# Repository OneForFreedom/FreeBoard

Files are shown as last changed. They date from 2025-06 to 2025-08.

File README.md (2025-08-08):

# FreeBoard
Freedom's Keyboard
This is my first keyboard! I had a blast desgining it and I'd thought I'd a nice black and red layout. This contains 3 rotary encoders cuz why not?

# Some cool mouthwatering visuals:

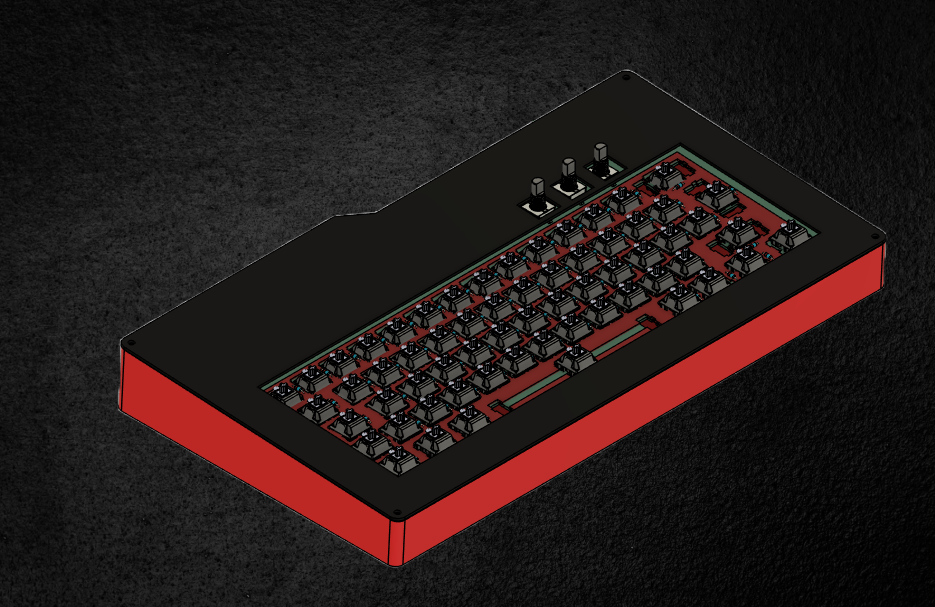
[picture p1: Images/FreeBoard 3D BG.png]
FreeBoard 3D BG
  
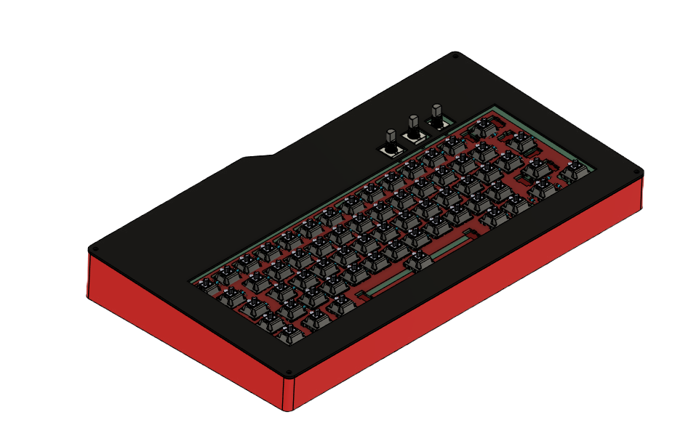
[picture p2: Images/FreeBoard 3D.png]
FreeBoard 3D
  
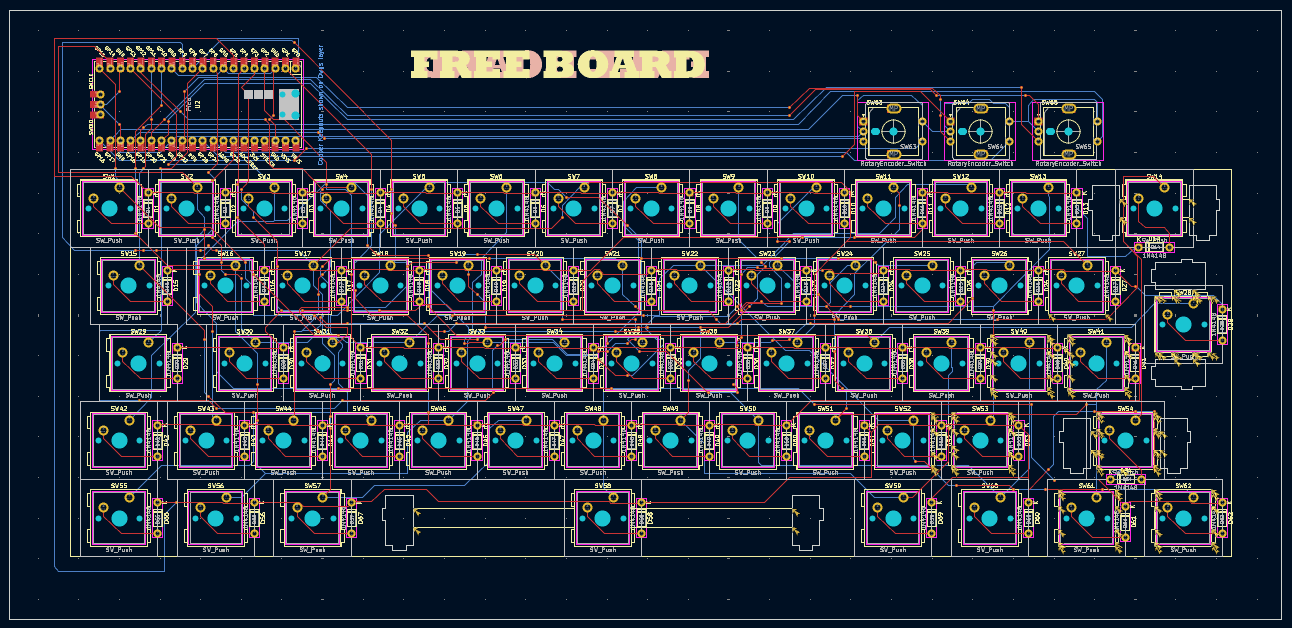
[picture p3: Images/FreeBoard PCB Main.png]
FreeBoard PCB Main
  
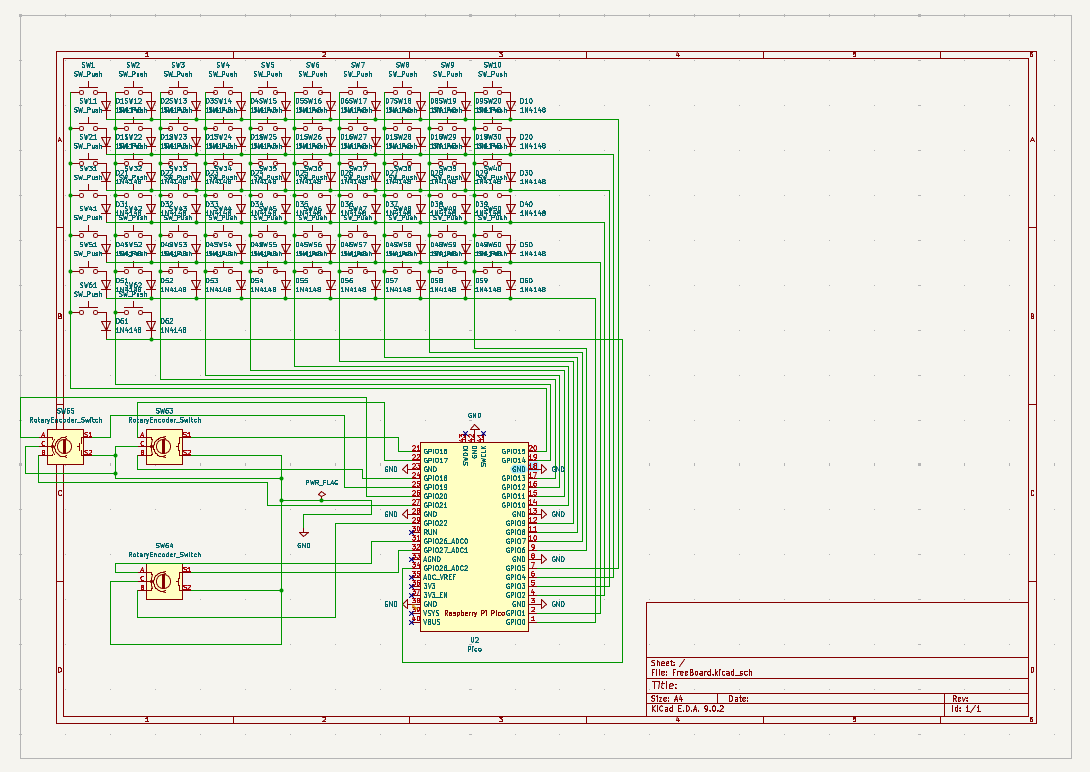
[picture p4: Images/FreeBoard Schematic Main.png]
FreeBoard Schematic Main
  
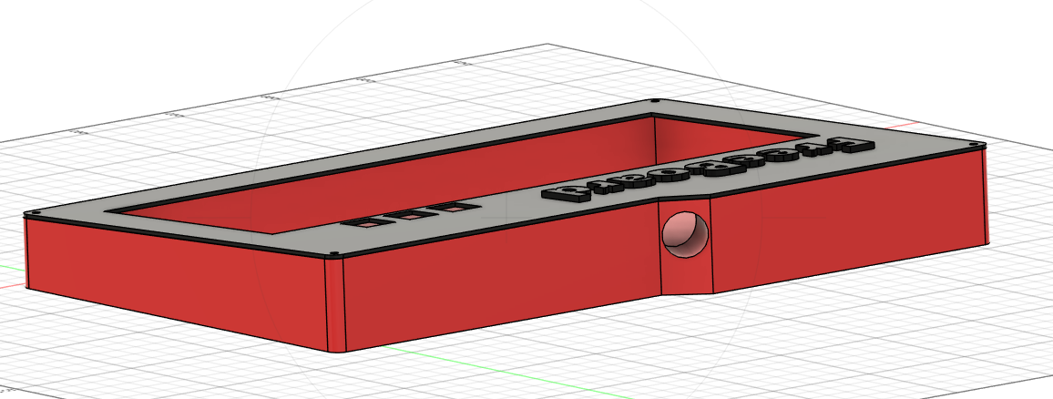
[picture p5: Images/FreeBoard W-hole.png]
FreeBoard Backside
  
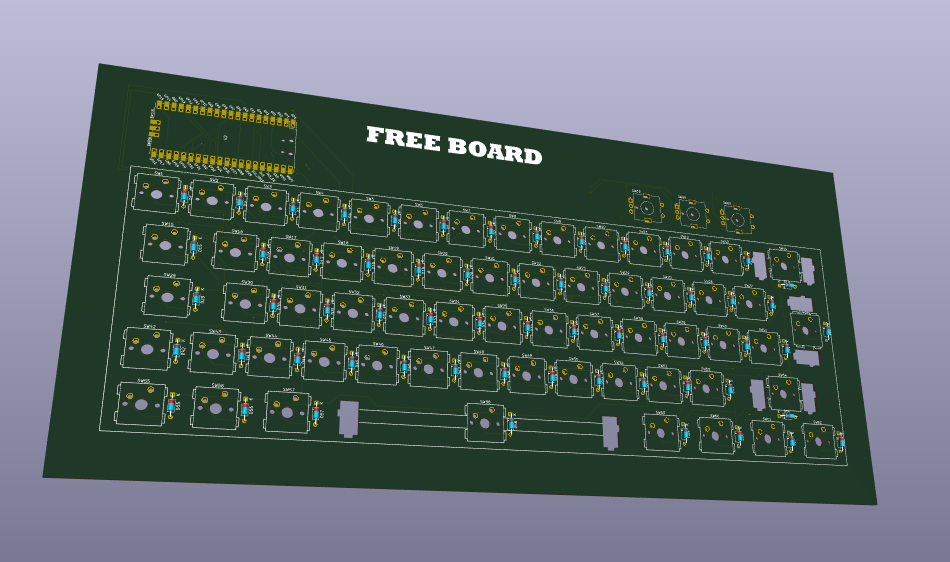
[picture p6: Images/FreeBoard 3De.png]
FreeBoard PCB 3D


# Bill Of Materials (BOM)

NEEDS COMPLETE REDO!

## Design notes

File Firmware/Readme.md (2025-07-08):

Basically this keyboard is a 60% uk iso keyboard (yes the one with the big upside down L)

The main keys are self explanatory.
The first rotary encoder (going from left) Does volumne control, twist it to adjust vol, and press it to mute/unmute it.
Second is for seeking tracks and pausing and playing, and 
third is null (idk what to do yet)

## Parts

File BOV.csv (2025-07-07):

Item | Quantity | Price (GBP) | Total (GBP) | Price (USD) | Total (USD) | Link
Pico Micro | 1 | 1.90 | 1.90 | 2.58 | 2.58 | https://www.aliexpress.com/item/1005008513003531.html?mp=1
Keycaps | 1 | 7.69 | 7.69 | 10.46 | 10.46 | https://www.aliexpress.com/item/1005004536761030.html?mp=1
O-Rings | 1 | 0.57 | 0.57 | 0.78 | 0.78 | https://www.aliexpress.com/item/32965363255.html?mp=1
Keyswitches | 1 | 21.39 | 21.39 | 29.09 | 29.09 | https://www.aliexpress.com/item/1005006425450443.html?mp=1
Cable | 1 | 0.92 | 0.92 | 1.25 | 1.25 | https://www.aliexpress.com/item/1005007138392516.html?mp=1
EC11 Cap | 1 | 1.06 | 1.06 | 1.44 | 1.44 | https://www.aliexpress.com/item/1005005983134515.html?mp=1
EC11 | 1 | 1.89 | 1.89 | 2.57 | 2.57 | https://www.aliexpress.com/item/1005005983134515.html?mp=1
Diodes (x3) | 3 | 0.70 | 2.10 | 0.95 | 2.86 | https://www.aliexpress.com/item/1005006245109375.html?mp=1
Switchpads | 1 | 2.52 | 2.52 | 3.43 | 3.43 | https://www.aliexpress.com/item/1005006454684461.html?mp=1
Switch Film | 1 | 2.00 | 2.00 | 2.72 | 2.72 | https://www.aliexpress.com/item/1005006584258877.html?mp=1
PCB | 1 | 28.65 | 28.65 | 38.95 | 38.95 | https://cart.jlcpcb.com/
Royal Mail Shipping | 1 | 5.00 | 5.00 | 6.80 | 6.80 | https://send.royalmail.com/send/youritem?country=GBR&format&weight=&weightUnit=G

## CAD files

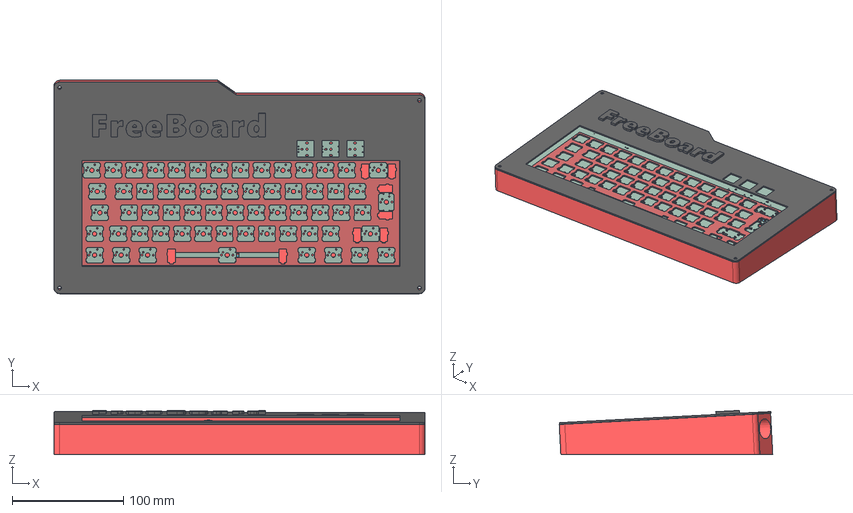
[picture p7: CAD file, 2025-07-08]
FreeBoard Assembled.step
333.0 x 191.7 x 39.6 mm
D_DO-35_SOD27_P7.62mm_Horizontal x 62
FreeBoard_PCB

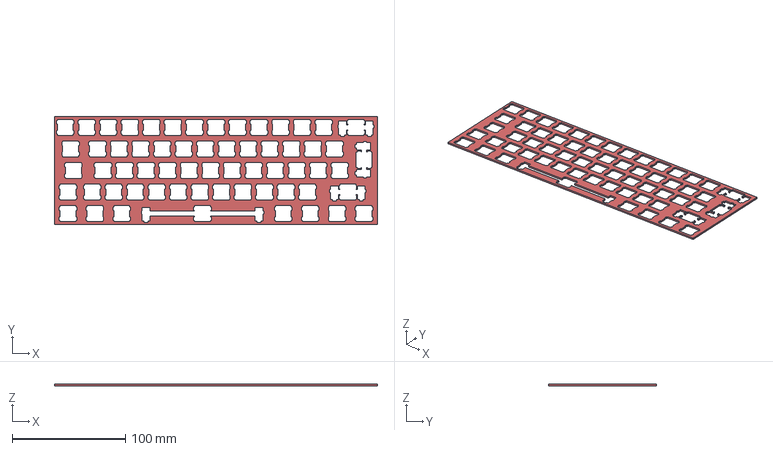
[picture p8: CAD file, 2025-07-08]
Cad/FreeBoard Plate.step
285.7 x 95.2 x 1.50 mm

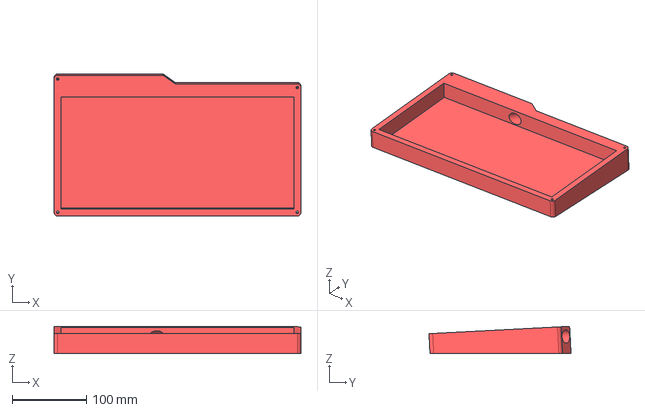
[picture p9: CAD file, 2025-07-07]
Production/FreeBoard Bottom.step
333.0 x 191.7 x 36.9 mm

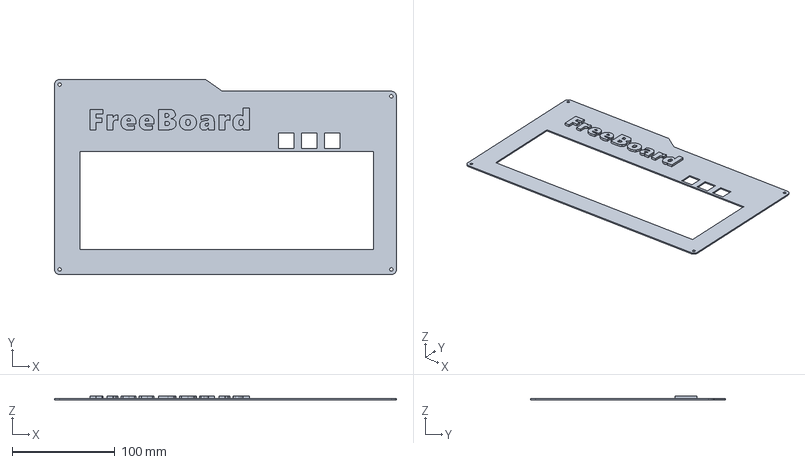
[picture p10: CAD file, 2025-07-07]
Production/FreeBoard Top.step
333.0 x 190.0 x 4.00 mm

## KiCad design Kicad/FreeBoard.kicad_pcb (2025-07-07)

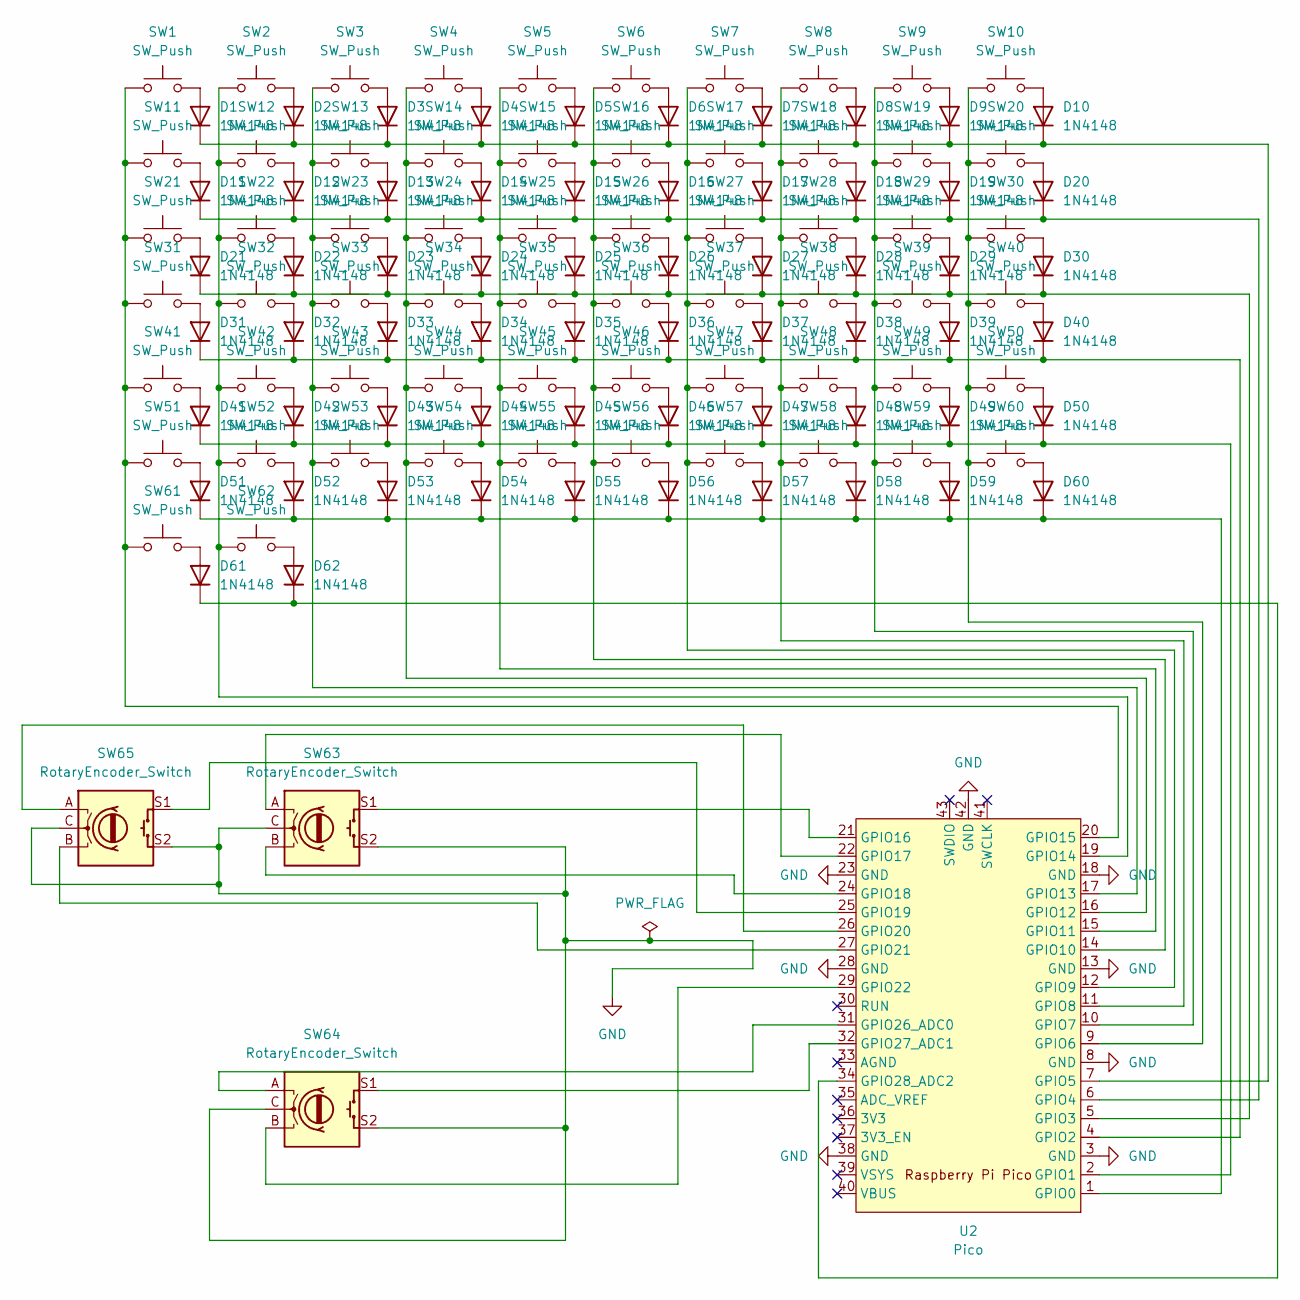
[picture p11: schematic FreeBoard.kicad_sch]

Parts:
D1, D2, D3, D4, D5, D6, D7, D8, D9, D10, D11, D12, D13, D14, D15, D16, D17, D18, D19, D20, D21, D22, D23, D24, D25, D26, D27, D28, D29, D30, D31, D32, D33, D34, D35, D36, D37, D38, D39, D40, D41, D42, D43, D44, D45, D46, D47, D48, D49, D50, D51, D52, D53, D54, D55, D56, D57, D58, D59, D60, D61, D62: 1N4148; D_DO-35_SOD27_P7.62mm_Horizontal
SW1, SW2, SW3, SW4, SW5, SW6, SW7, SW8, SW9, SW10, SW11, SW12, SW13, SW14, SW15, SW16, SW17, SW18, SW19, SW20, SW21, SW22, SW23, SW24, SW25, SW26, SW27, SW28, SW29, SW30, SW31, SW32, SW33, SW34, SW35, SW36, SW37, SW38, SW39, SW40, SW41, SW42, SW43, SW44, SW45, SW46, SW47, SW48, SW49, SW50, SW51, SW52, SW53, SW54, SW55, SW56, SW57, SW58, SW59, SW60, SW61, SW62: SW_Push; SW_Cherry_MX_1.00u_PCB
SW63, SW64, SW65: RotaryEncoder_Switch; RotaryEncoder_Alps_EC11E-Switch_Vertical_H20mm_MountingHoles
U2: Pico; RPi_Pico_SMD_TH

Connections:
GND: SW63.C, SW63.S2, SW64.C, SW64.S2, SW65.C, SW65.S2, U2.3 (GND), U2.8 (GND), U2.13 (GND), U2.18 (GND), U2.23 (GND), U2.28 (GND), U2.38 (GND), U2.42 (GND)
unnamed: D1.2 (A), SW1.2
unnamed: D1.1 (K), D2.1 (K), D3.1 (K), D4.1 (K), D5.1 (K), D6.1 (K), D7.1 (K), D8.1 (K), D9.1 (K), D10.1 (K), U2.7 (GPIO5)
unnamed: D2.2 (A), SW2.2
unnamed: D3.2 (A), SW3.2
unnamed: D4.2 (A), SW4.2
unnamed: D5.2 (A), SW5.2
unnamed: D6.2 (A), SW6.2
unnamed: D7.2 (A), SW7.2
unnamed: D8.2 (A), SW8.2
unnamed: D9.2 (A), SW9.2
unnamed: D10.2 (A), SW10.2
unnamed: D11.2 (A), SW11.2
unnamed: D11.1 (K), D12.1 (K), D13.1 (K), D14.1 (K), D15.1 (K), D16.1 (K), D17.1 (K), D18.1 (K), D19.1 (K), D20.1 (K), U2.6 (GPIO4)
unnamed: D12.2 (A), SW12.2
unnamed: D13.2 (A), SW13.2
unnamed: D14.2 (A), SW14.2
unnamed: D15.2 (A), SW15.2
unnamed: D16.2 (A), SW16.2
unnamed: D17.2 (A), SW17.2
unnamed: D18.2 (A), SW18.2
unnamed: D19.2 (A), SW19.2
unnamed: D20.2 (A), SW20.2
unnamed: D21.2 (A), SW21.2
unnamed: D21.1 (K), D22.1 (K), D23.1 (K), D24.1 (K), D25.1 (K), D26.1 (K), D27.1 (K), D28.1 (K), D29.1 (K), D30.1 (K), U2.5 (GPIO3)
unnamed: D22.2 (A), SW22.2
unnamed: D23.2 (A), SW23.2
unnamed: D24.2 (A), SW24.2
unnamed: D25.2 (A), SW25.2
unnamed: D26.2 (A), SW26.2
unnamed: D27.2 (A), SW27.2
unnamed: D28.2 (A), SW28.2
unnamed: D29.2 (A), SW29.2
unnamed: D30.2 (A), SW30.2
unnamed: D31.2 (A), SW31.2
unnamed: D31.1 (K), D32.1 (K), D33.1 (K), D34.1 (K), D35.1 (K), D36.1 (K), D37.1 (K), D38.1 (K), D39.1 (K), D40.1 (K), U2.4 (GPIO2)
unnamed: D32.2 (A), SW32.2
unnamed: D33.2 (A), SW33.2
unnamed: D34.2 (A), SW34.2
unnamed: D35.2 (A), SW35.2
unnamed: D36.2 (A), SW36.2
unnamed: D37.2 (A), SW37.2
unnamed: D38.2 (A), SW38.2
unnamed: D39.2 (A), SW39.2
unnamed: D40.2 (A), SW40.2
unnamed: D41.2 (A), SW41.2
unnamed: D41.1 (K), D42.1 (K), D43.1 (K), D44.1 (K), D45.1 (K), D46.1 (K), D47.1 (K), D48.1 (K), D49.1 (K), D50.1 (K), U2.2 (GPIO1)
unnamed: D42.2 (A), SW42.2
unnamed: D43.2 (A), SW43.2
unnamed: D44.2 (A), SW44.2
unnamed: D45.2 (A), SW45.2
unnamed: D46.2 (A), SW46.2
unnamed: D47.2 (A), SW47.2
unnamed: D48.2 (A), SW48.2
unnamed: D49.2 (A), SW49.2
unnamed: D50.2 (A), SW50.2
unnamed: D51.2 (A), SW51.2
unnamed: D51.1 (K), D52.1 (K), D53.1 (K), D54.1 (K), D55.1 (K), D56.1 (K), D57.1 (K), D58.1 (K), D59.1 (K), D60.1 (K), U2.1 (GPIO0)
unnamed: D52.2 (A), SW52.2
unnamed: D53.2 (A), SW53.2
unnamed: D54.2 (A), SW54.2
unnamed: D55.2 (A), SW55.2
unnamed: D56.2 (A), SW56.2
unnamed: D57.2 (A), SW57.2
unnamed: D58.2 (A), SW58.2
unnamed: D59.2 (A), SW59.2
unnamed: D60.2 (A), SW60.2
unnamed: D61.2 (A), SW61.2
unnamed: D61.1 (K), D62.1 (K), U2.34 (GPIO28_ADC2)
unnamed: D62.2 (A), SW62.2
unnamed: SW10.1, SW20.1, SW30.1, SW40.1, SW50.1, SW60.1, U2.9 (GPIO6)
unnamed: SW9.1, SW19.1, SW29.1, SW39.1, SW49.1, SW59.1, U2.10 (GPIO7)
unnamed: SW8.1, SW18.1, SW28.1, SW38.1, SW48.1, SW58.1, U2.11 (GPIO8)
unnamed: SW7.1, SW17.1, SW27.1, SW37.1, SW47.1, SW57.1, U2.12 (GPIO9)
unnamed: SW6.1, SW16.1, SW26.1, SW36.1, SW46.1, SW56.1, U2.14 (GPIO10)
unnamed: SW5.1, SW15.1, SW25.1, SW35.1, SW45.1, SW55.1, U2.15 (GPIO11)
unnamed: SW4.1, SW14.1, SW24.1, SW34.1, SW44.1, SW54.1, U2.16 (GPIO12)
unnamed: SW3.1, SW13.1, SW23.1, SW33.1, SW43.1, SW53.1, U2.17 (GPIO13)
unnamed: SW2.1, SW12.1, SW22.1, SW32.1, SW42.1, SW52.1, SW62.1, U2.19 (GPIO14)
unnamed: SW1.1, SW11.1, SW21.1, SW31.1, SW41.1, SW51.1, SW61.1, U2.20 (GPIO15)
unnamed: SW63.S1, U2.21 (GPIO16)
unnamed: SW63.A, U2.22 (GPIO17)
unnamed: SW63.B, U2.24 (GPIO18)
unnamed: SW65.S1, U2.25 (GPIO19)
unnamed: SW65.A, U2.26 (GPIO20)
unnamed: SW65.B, U2.27 (GPIO21)
unnamed: SW64.B, U2.29 (GPIO22)
unnamed: SW64.A, U2.31 (GPIO26_ADC0)
unnamed: SW64.S1, U2.32 (GPIO27_ADC1)

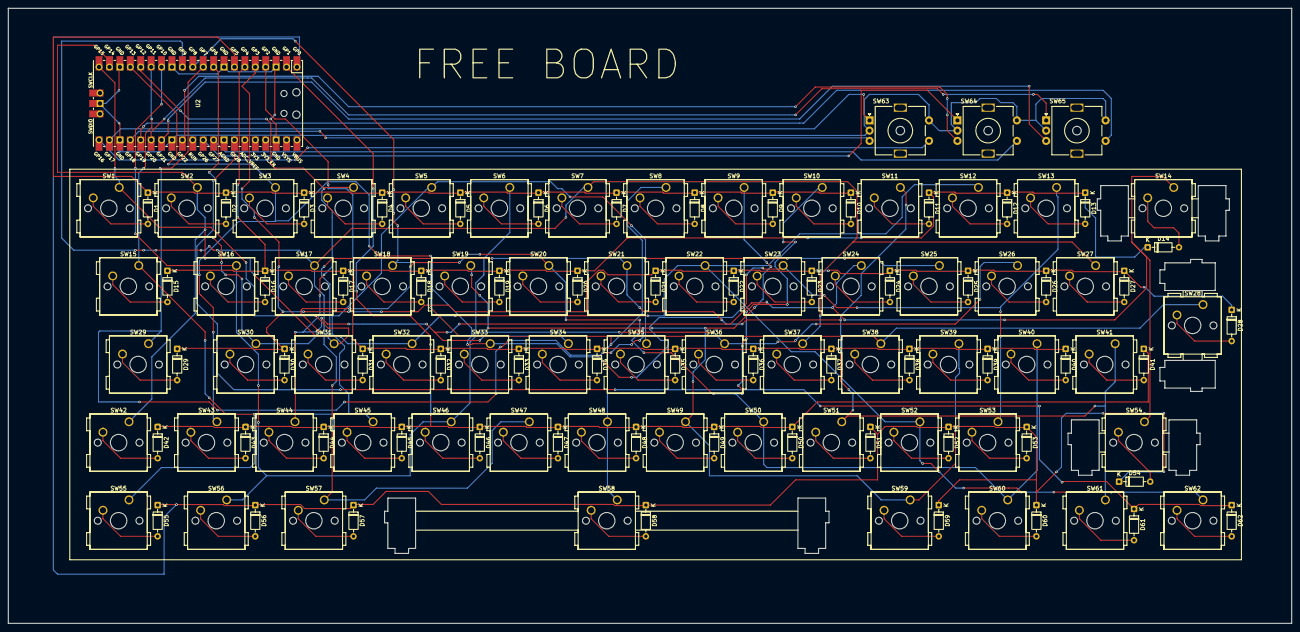
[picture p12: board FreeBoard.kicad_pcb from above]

Board: 2 copper layers, 313.0 x 150.0 mm, 128 parts (0 on the bottom side), 89 nets.

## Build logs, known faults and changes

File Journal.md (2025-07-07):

TOTAL TIME TAKEN! 24H 10 MIN

---
title: "FreeBoard"
author: "One For Freedom"
description: "Basically just a 60% keyboard with three rotary encoders."
created_at: "2024-06-29"
---

# June 30th : Started the build!

[I made a schematic today and completed footprints. I also researched parts. I'm using a raspberry pi pico, which is like 5 us dollars, I also found switches which are 110 for 60ish dollars, I know its a bit steep, but I can't afford getting super bad low quality ones after a month of waiting. I also found.. Well, nothing, I was looking for keycaps but realised that you can't get good ones for 10 dollars. I'll have to save the search for keycaps later. I'm gonna have to look for two rotary encoders and 62 diodes.
Peace!]

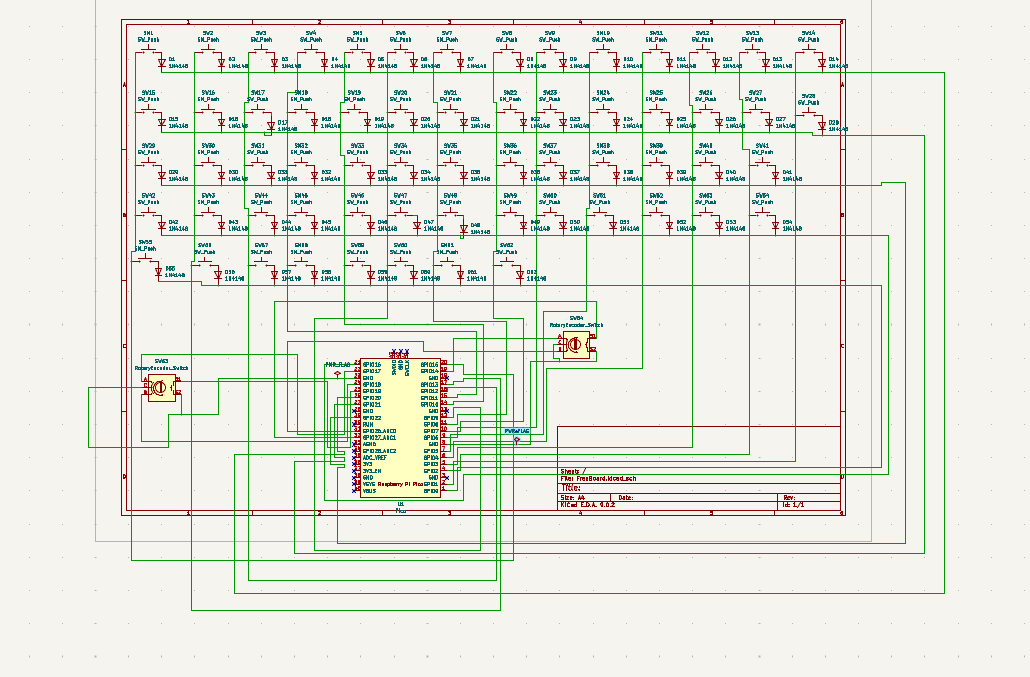
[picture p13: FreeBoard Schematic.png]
FreeBoard Schematic


**Total time spent: 3h 10m**

# Jul 1 : Finished the schematic!

[Bruh, I rebuilt the schematic, I changed the layout from 14x5 to 7x10 so that I could add an extra rotary encoder - 100% worth it. I decided that I'm gonna 3d print keycaps along with rotary encoder knobs cases and any basic tools ill need. Tomorrow I'll finalise the items I'll need and the prices.]

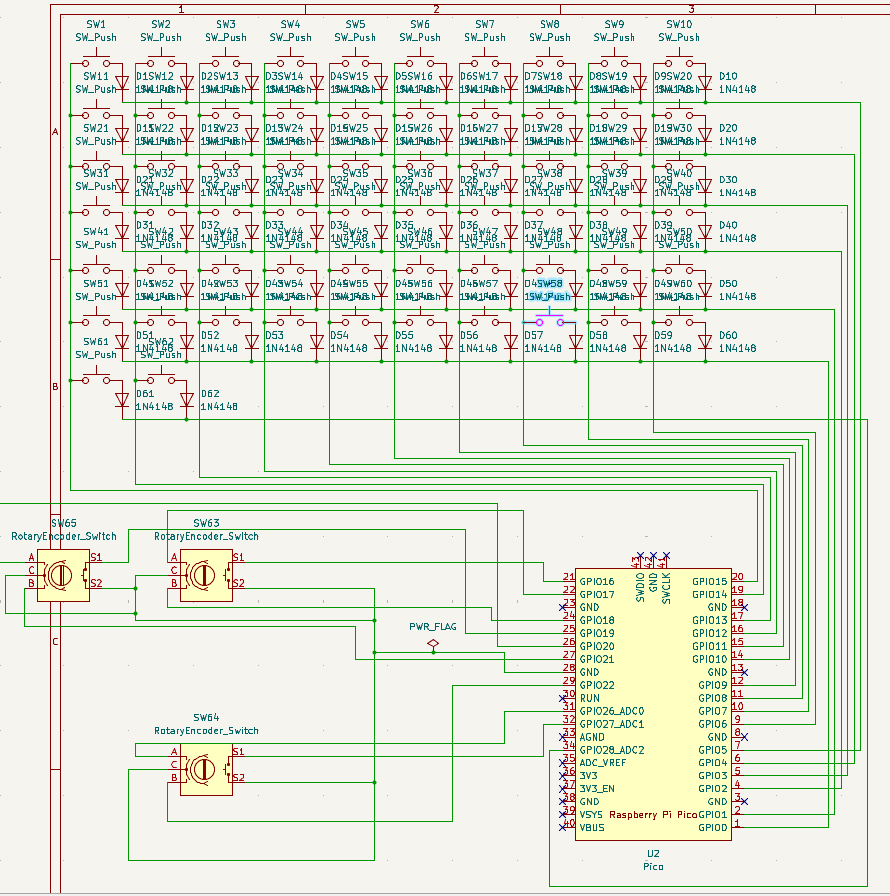
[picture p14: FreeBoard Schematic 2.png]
Freeboard Second Schematic


**Time spent : 4h**

# Jul 2nd : PCB COMPLETE, ITEM HUNT ALSO COMPLETE!

[LETS GOOO! THE PCB IS DONE!! now I got to do the most taxing job, the case. itll be pain but ill make it through, Honestly i might go for a tilted case ykyk. I'll show you the pcb down below. I also had to painstakinly add holes for clip in stabilizers - I'm too
scared to add screw hole in, so screw that, also since im using an iso layout, i'll have to add a 2.75u wire to the stabiliser, which is impossible to find, so I needed to get them "compatible" ones. I made the keycaps (i love google) and also a plate (idk how'll that go on, if i completely mess it up, then it'll be a plateless project.) Here's an itemised bill: (Prices may fluxuate depending on conversion rates and inflation)]
| Item | Pounds (£) | Conversion Rate | Dollars (\$) |
| --- | --- | --- | --- |
| PCB (Freeboard) | 25.09 | × 1.36 | 34.52 |
| Raspberry Pi | 7.70 | × 1.36 | 10.47 |
| Switches | 24.98 | × 1.36 | 33.97 |
| Rotary Encoders (9.20€) | \~7.93 | × 1.36 | 10.78 |
| Stabilizers + Shipping  | 20.91 | × 1.36 | 28.44 |
| Diodes | 6.06 | × 1.36 | 8.24 |
| Royal Mail Shipping | 5.00 | × 1.36 | 6.80 |
| Micro USB Cable | 3.00 | × 1.36 | 4.08 |
| Grand Total | | | ~137.30 |

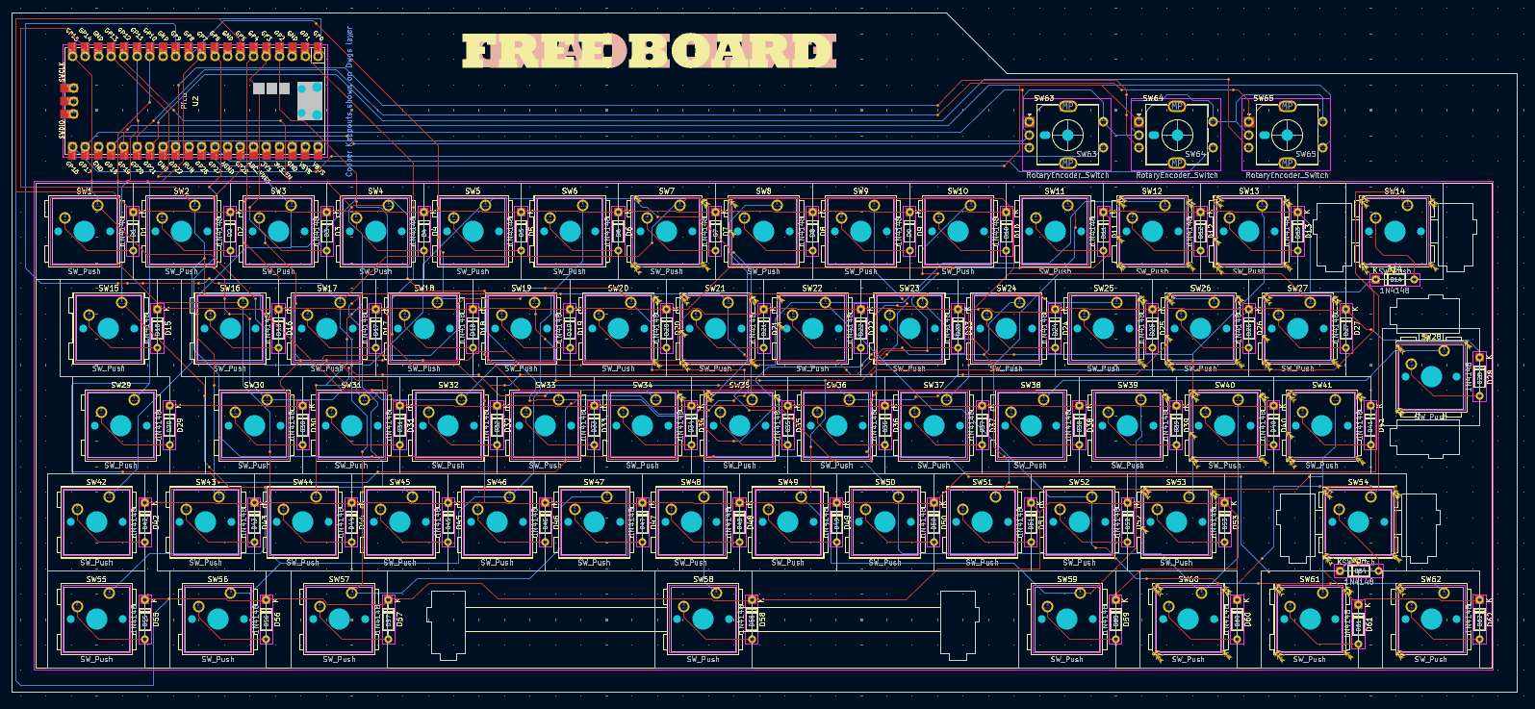
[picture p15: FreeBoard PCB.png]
FreeBoard PCB


**Time spent 6 Hours**

# Jul 6th : Back to business.

I did one big project, but that got quickly scrapped when I realised It was only a 4 point project, I might continue it after following the discovery of ALiExpress.
I submitted another project which was basically an etchasketch but it was digital. And suprisingly, I did it in under one day! Now enough for that, time for this.

I left off after finishing the pcb. But now I started with the cad. But now I got to go bed, so cya, Bigger update tomorrow.

**Time Spent: 1 Hour**

# Jul 7th : COMPLETION

All softwarical (if thats a word) projects are done! 
Now let me submit this. The cad was done which was relatively easy, but it's big af, cad crashed on me midway saving, but luckily I saved it before it did.
Now lets talk prices, let me run this with my super cool mathmatical skills and I'll get back to you.

# Bill Of Materials (BOM)

| Item | Quantity | Price (GBP) | Total (GBP) | Price (USD) | Total (USD) | Link |
|---|---|---|---|---|---|---|
| Pico Micro | 1 | £1.90 | £1.90 | $2.58 | $2.58 | [Link](https://www.aliexpress.com/item/1005008513003531.html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) |
| Keycaps | 1 | £7.69 | £7.69 | $10.46 | $10.46 | [Link](https://www.aliexpress.com/item/1005004536761030.html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) |
| O-Rings | 1 | £0.57 | £0.57 | $0.78 | $0.78 | [Link](https://www.aliexpress.com/item/32965363255.html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) |
| Keyswitches | 1 | £21.39 | £21.39 | $29.09 | $29.09 | [Link](https://www.aliexpress.com/item/1005006425450443.html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) |
| Cable | 1 | £0.92 | £0.92 | $1.25 | $1.25 | [Link](https://www.aliexpress.com/item/1005007138392516.html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) |
| EC11 Cap | 1 | £1.06 | £1.06 | $1.44 | $1.44 | [Link](https://www.aliexpress.com/item/1005005983134515.html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) |
| EC11 | 1 | £1.89 | £1.89 | $2.57 | $2.57 | [Link](https://www.aliexpress.com/item/1005005983134515.html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) |
| Diodes (x3) | 3 | £0.70 | £2.10 | $0.95 | $2.86 | [Link](https://www.aliexpress.com/item/1005006245109375.html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) |
| Switchpads | 1 | £2.52 | £2.52 | $3.43 | $3.43 | [Link](https://www.aliexpress.com/item/1005006454684461.html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) |
| Switch Film | 1 | £2.00 | £2.00 | $2.72 | $2.72 | [Link](https://www.aliexpress.com/item/1005006584258877.html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) |
| PCB | 1 | £28.65 | £28.65 | $38.95 | $38.95 | [Link](https://cart.jlcpcb.com/) |
| Royal Mail Shipping | 1 | £5.00 | £5.00 | $6.80 | $6.80 | [Link](https://send.royalmail.com/send/youritem?country=GBR&format&weight=&weightUnit=G) |

**Grand Total (GBP): £74.69**  
**Grand Total (USD): $101.55**

Time Taken : 10 Hours (Ikr)

I'm soo happy !!!

I'll cya UNTIL EVERYTHING ARRIVES!

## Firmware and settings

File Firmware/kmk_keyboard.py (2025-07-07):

import board
from kmk.kmk_keyboard import KMKKeyboard
from kmk.keys import KC
from kmk.scanners import DiodeOrientation
from kmk.extensions.media_keys import MediaKeys
from kmk.handlers.sequences import send_string
from kmk.modules.encoder import EncoderHandler

keyboard = KMKKeyboard()
keyboard.extensions.append(MediaKeys())

# Encoder Setup
encoders = EncoderHandler()
keyboard.modules.append(encoders)

encoders.pins = [
    (board.GP2, board.GP3),  # Encoder 1
    (board.GP4, board.GP5),  # Encoder 2
    (board.GP6, board.GP7),  # Encoder 3
]

encoders.map = [
    ((KC.MPRV, KC.MNXT), KC.MPLY),  # Encoder 1: Prev/Next, press = Play/Pause
    ((KC.VOLD, KC.VOLU), KC.MUTE), # Encoder 2: Volume down/up, press = Mute
    ((KC.NO, KC.NO), KC.NO),       # Encoder 3: Unused
]

# Matrix setup (example GP pins)
keyboard.col_pins = (board.GP0, board.GP1, board.GP2, board.GP3, board.GP4, board.GP5, board.GP6, board.GP7, board.GP8, board.GP9)
keyboard.row_pins = (board.GP10, board.GP11, board.GP12, board.GP13, board.GP14, board.GP15, board.GP16)
keyboard.diode_orientation = DiodeOrientation.COL2ROW  # Mostly column-side

# This is a placeholder layout; we’ll replace it with your exact 62-key UK ISO layout
keyboard.keymap = [
    [
        KC.ESC,  KC.N1,    KC.N2,    KC.N3,   KC.N4,   KC.N5,   KC.N6,   KC.N7,   KC.N8,   KC.N9,
        KC.N0,   KC.MINS,  KC.EQL,  KC.BSPC, KC.TAB,  KC.Q,    KC.W,    KC.E,    KC.R,    KC.T,
        KC.Y,    KC.U,     KC.I,    KC.O,   KC.P,    KC.LBRC, KC.RBRC, KC.ENT,  KC.LSFT, KC.A,
        KC.S,    KC.D,     KC.F,    KC.G,   KC.H,    KC.J,    KC.K,    KC.L,    KC.SCLN, KC.QUOT,
        KC.NUHS, KC.LSFT,  KC.Z,    KC.X,   KC.C,    KC.V,    KC.B,    KC.N,    KC.M,    KC.COMM,
        KC.DOT,  KC.SLSH,  KC.RSFT, KC.LCTL, KC.LGUI, KC.LALT, KC.SPC, KC.RALT, KC.RGUI, KC.MO(1),
    ]
]

if __name__ == '__main__':
    keyboard.go()

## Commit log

2025-07-07 Rename b23b2af1c99153fe488ddd7cfa8304c6e30416d8_mx_.step to Cherry Mx
    [b23b2af1c99153fe488ddd7cfa8304c6e30416d8_mx_.step]
2025-07-07 Rename b23b2af1c99153fe488ddd7cfa8304c6e30416d8_mx_ (1).step to Cherry MX
    [b23b2af1c99153fe488ddd7cfa8304c6e30416d8_mx_ (1).step]
2025-07-07 Rename Screenshot 2025-07-08 000822.png to FreeBoard W-hole.png
2025-07-08 Update and rename FreeBoard Bottom.step to Cad/FreeBoard Bottom.step
    [FreeBoard Bottom.step]
2025-07-08 Update and rename FreeBoard Top.step to Cad/FreeBoard Top.step
    [FreeBoard Top.step]
2025-07-08 Rename FreeBoard PCB Main.png to Images/FreeBoard PCB Main.png
2025-07-08 Rename FreeBoard PCB.png to Images/FreeBoard PCB.png
2025-07-08 Rename FreeBoard Schematic 2.png to Images/FreeBoard Schematic 2.png
2025-07-08 Rename FreeBoard Schematic Main.png to Images/FreeBoard Schematic Main.png
2025-07-08 Rename FreeBoard Schematic.png to Images/FreeBoard Schematic.png
2025-07-08 Rename FreeBoard W-hole.png to Images/FreeBoard W-hole.png
2025-07-08 Update and rename Raspberry Pi Pico-R3.STEP to Cad/Raspberry Pi Pico-R3.STEP
    [Raspberry Pi Pico-R3.STEP]
2025-07-08 Update and rename FreeBoard.kicad_pcb to Kicad/FreeBoard.kicad_pcb
    [FreeBoard.kicad_pcb]
2025-07-08 Update and rename FreeBoard.kicad_sch to Kicad/FreeBoard.kicad_sch
    [FreeBoard.kicad_sch]
2025-07-08 Update and rename FreeBoard Bottom.step to Production/FreeBoard Bottom.step
    [FreeBoard Bottom.step]
2025-07-08 Update and rename FreeBoard Plate.step to Production/FreeBoard Plate.step
    [FreeBoard Plate.step]
2025-07-08 Update and rename FreeBoard Top.step to Production/FreeBoard Top.step
    [FreeBoard Top.step]
2025-07-08 Update and rename FreeBoard Plate.step to Cad/FreeBoard Plate.step
    [FreeBoard Plate.step]
2025-07-08 Rename FreeBoard Assembled.zip to Cad/FreeBoard Assembled.zip
2025-07-08 Rename FreeBoard Assembled.zip to Production/FreeBoard Assembled.zip
2025-07-08 Rename FreeBoard Final Assembly.zip to Cad/FreeBoard Final Assembly.zip
2025-07-08 Rename FreeBoard Assembled.step to Cad/FreeBoard Assembled.step
    [FreeBoard Assembled.step]
